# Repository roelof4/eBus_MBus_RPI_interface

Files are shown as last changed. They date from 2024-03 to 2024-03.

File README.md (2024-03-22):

# eBus_MBus_RPI_interface
Raspberry PI interface for eBus and M-Bus.

The interface combines a slave eBus interface and a master Mbus interface. This combination
is often present in heating systems such as gas boilers and heatpumps. For example, Vaillant
uses eBus to read and control.
The Mbus master is ideal to read heat meters, water meters and other sensors.
This interface provides power to the sensors and is thus classified as the master.
For safety purposes the eBus interface is fully galvanically shielded using optocouplers.

Both interfaces can be linked to serial (UART) ports on the Raspberry Pi. Version 4 and beyond
provide more than two UARTS and the user can select which one is used for either interface.
Older Raspberries can typically only use one UART. For these case the user can use serial to usb
cables using a separate 4-pin connector. Two are provided such that in principle the board
can be used standalone provided a 5V powersupply is present. When mounted as a HAT on the
Raspberry the 5V supply provided through the GPIO connector is used.

The interface also features a ONE WIRE sensor screw terminal which can act as a multiple temperature
sensor input (or whatever other ONE WIRE device available).

Note: the I2C EEPROM is optional and used for a system with automatic recognition.

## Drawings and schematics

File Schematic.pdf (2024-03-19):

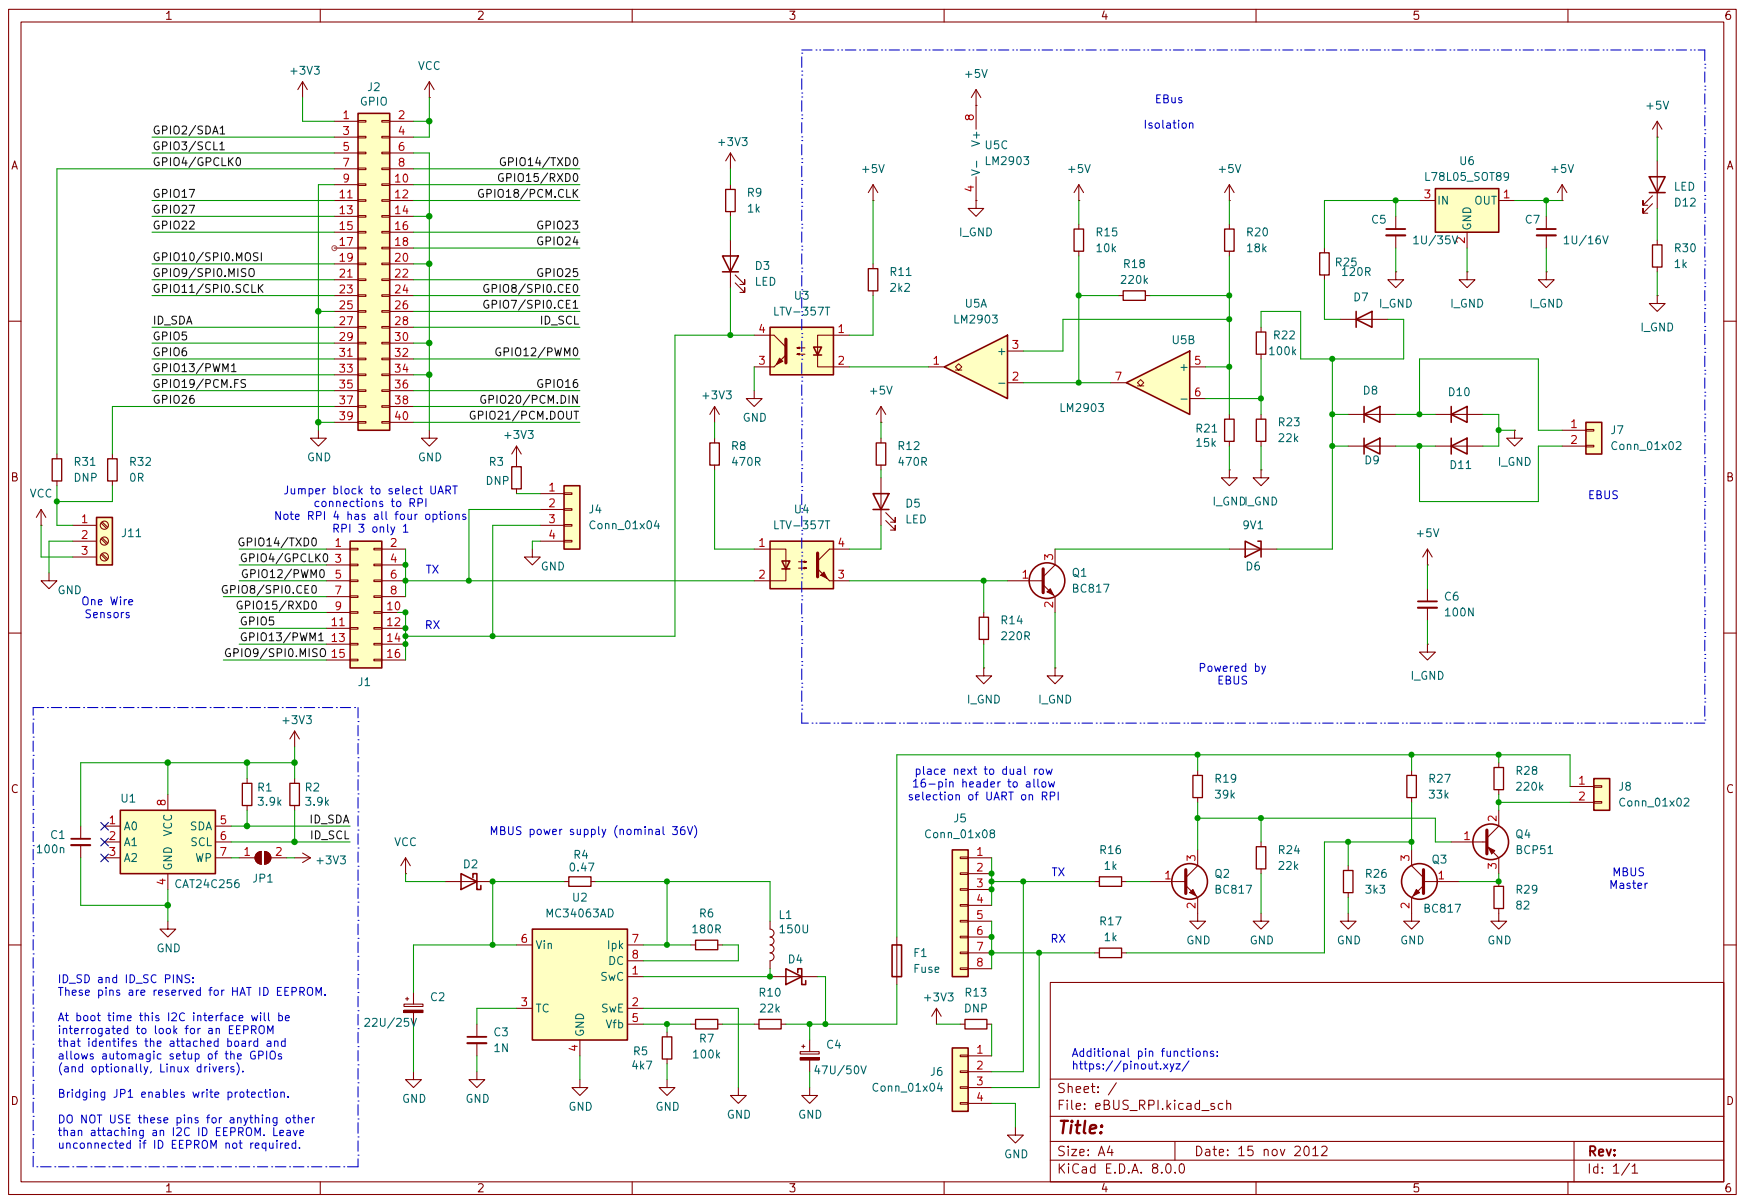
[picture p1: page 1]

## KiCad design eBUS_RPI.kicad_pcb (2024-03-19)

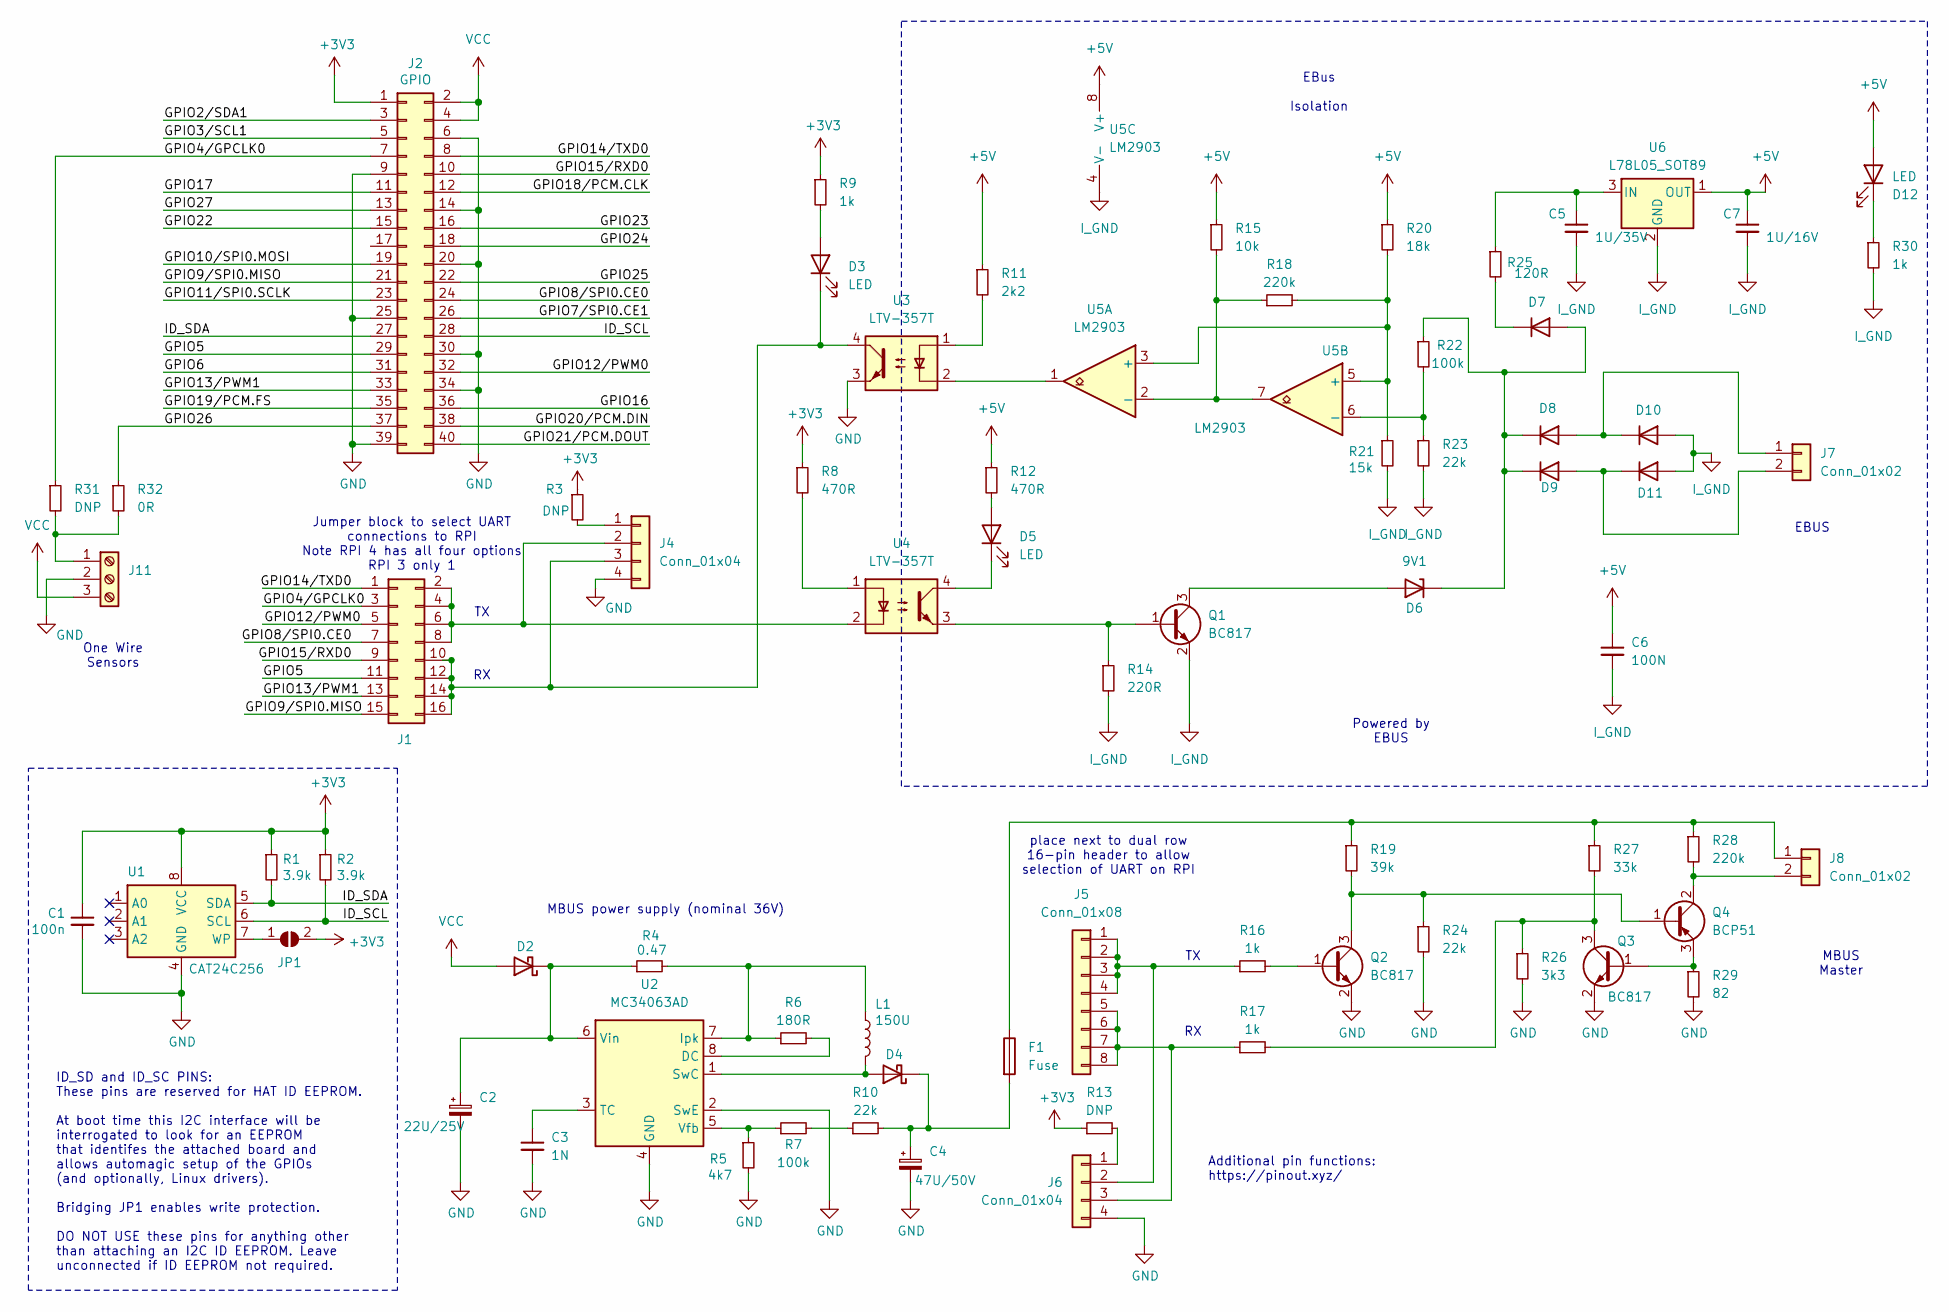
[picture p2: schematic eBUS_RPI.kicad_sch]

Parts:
C1: 100n; R_0603_1608Metric
C2: 22U/25V; CP_Elec_5x3.9
C3: 1N; C_0603_1608Metric
C4: 47U/50V; CP_Elec_5x5.7
C5: 1U/35V; C_0603_1608Metric
C6: 100N; C_0603_1608Metric
C7: 1U/16V; C_0603_1608Metric
D2, D4: D_Schottky; D_SMA
D3, D5, D12: LED; LED_0805_2012Metric
D6: 9V1; D_SMC
D7, D8, D9, D10, D11: BAS16W; SOT-323_SC-70
F1: Fuse; Fuse_2920_7451Metric
J1: Conn_02x08_Odd_Even; PinHeader_2x08_P2.54mm_Vertical
J2: GPIO; PinSocket_2x20_P2.54mm_Vertical
J4, J6: Conn_01x04; PinHeader_1x04_P2.54mm_Vertical
J5: Conn_01x08; PinHeader_1x08_P2.54mm_Vertical
J7, J8: Conn_01x02; PhoenixContact_MSTBA_2,5_2-G-5,08_1x02_P5.08mm_Horizontal
J11: Screw_Terminal_01x03; TerminalBlock_Phoenix_PT-1,5-3-5.0-H_1x03_P5.00mm_Horizontal
JP1: ID_WP; SolderJumper-2_P1.3mm_Open_TrianglePad1.0x1.5mm
L1: 150U; L_7.3x7.3_H4.5
Q1, Q2, Q3: BC817; SOT-23
Q4: BCP51; SOT-223-3_TabPin2
R1, R2: 3.9k; R_0603_1608Metric
R3, R13, R31: DNP; R_0603_1608Metric
R4: 0.47; R_0603_1608Metric
R5: 4k7; R_0603_1608Metric
R6: 180R; R_0603_1608Metric
R7, R22: 100k; R_0603_1608Metric
R8, R12: 470R; R_0603_1608Metric
R9, R16, R17, R30: 1k; R_0603_1608Metric
R10, R23, R24: 22k; R_0603_1608Metric
R11: 2k2; R_0603_1608Metric
R14: 220R; R_0603_1608Metric
R15: 10k; R_0603_1608Metric
R18, R28: 220k; R_0603_1608Metric
R19: 39k; R_0603_1608Metric
R20: 18k; R_0603_1608Metric
R21: 15k; R_0603_1608Metric
R25: 120R; R_0603_1608Metric
R26: 3k3; R_0603_1608Metric
R27: 33k; R_0603_1608Metric
R29: 82; R_0603_1608Metric
R32: 0R; R_0603_1608Metric
U1: CAT24C256; SOIC-8_3.9x4.9mm_P1.27mm
U2: MC34063AD; SOIC-8_3.9x4.9mm_P1.27mm
U3, U4: LTV-357T; SO-4_4.4x3.6mm_P2.54mm
U5: LM2903; SOIC-8_3.9x4.9mm_P1.27mm
U6: L78L05_SOT89; SOT-89-3

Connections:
+3V3: C1.1, J2.1, JP1.2 (B), R1.1, R2.1, R3.1, R8.1, R9.1, R13.1, U1.8 (VCC)
+5V: C6.1, C7.1, D12.2 (A), R11.1, R12.1, R15.1, R20.1, U5.8 (V+), U6.1 (OUT)
/GPIO2/SDA1: J2.3
/GPIO3/SCL1: J2.5
/GPIO4/GPCLK0: J1.3, J2.7, R31.1
/GPIO5: J1.11, J2.29
/GPIO6: J2.31
/GPIO7/SPI0.CE1: J2.26
/GPIO8/SPI0.CE0: J1.7, J2.24
/GPIO9/SPI0.MISO: J1.15, J2.21
/GPIO10/SPI0.MOSI: J2.19
/GPIO11/SPI0.SCLK: J2.23
/GPIO12/PWM0: J1.5, J2.32
/GPIO13/PWM1: J1.13, J2.33
/GPIO14/TXD0: J1.1, J2.8
/GPIO15/RXD0: J1.9, J2.10
/GPIO16: J2.36
/GPIO17: J2.11
/GPIO18/PCM.CLK: J2.12
/GPIO19/PCM.FS: J2.35
/GPIO20/PCM.DIN: J2.38
/GPIO21/PCM.DOUT: J2.40
/GPIO22: J2.15
/GPIO23: J2.16
/GPIO24: J2.18
/GPIO25: J2.22
/GPIO26: J2.37, R32.1
/GPIO27: J2.13
/ID_SCL: J2.28, R2.2, U1.6 (SCL)
/ID_SDA: J2.27, R1.2, U1.5 (SDA)
GND: C1.2, C2.2, C3.2, C4.2, J2.6, J2.9, J2.14, J2.20, J2.25, J2.30, J2.34, J2.39, J4.4, J6.4, J11.2, Q2.2 (E), Q3.2 (E), R5.2, R24.2, R26.2, R29.2, U1.4 (GND), U2.2 (SwE), U2.4 (GND), U3.3
I_GND: C5.2, C6.2, C7.2, D10.1 (A), D11.1 (A), Q1.2 (E), R14.2, R21.2, R23.2, R30.2, U5.4 (V-), U6.2 (GND)
unnamed: C2.1, D2.1 (K), R4.1, U2.6 (Vin)
unnamed: D3.2 (A), R9.2
unnamed: D3.1 (K), J1.10, J1.12, J1.14, J1.16, J4.3, U3.4
unnamed: D4.2 (A), L1.2, U2.1 (SwC)
unnamed: C4.1, D4.1 (K), F1.2, R10.2
unnamed: D5.2 (A), R12.2
unnamed: D5.1 (K), U4.4
unnamed: D6.2 (A), Q1.3 (C)
unnamed: D6.1 (K), D7.1 (A), D8.3 (K), D9.3 (K), R22.1
unnamed: D7.3 (K), R25.2
unnamed: D8.1 (A), D10.3 (K), J7.1
unnamed: D9.1 (A), D11.3 (K), J7.2
unnamed: D12.1 (K), R30.1
unnamed: J1.2, J1.4, J1.6, J1.8, J4.2, U4.2
unnamed: J4.1, R3.2
unnamed: J5.1, J5.2, J5.3, J5.4, J6.2, R16.1
unnamed: J5.5, J5.6, J5.7, J5.8, J6.3, R17.1
unnamed: J6.1, R13.2
unnamed: F1.1, J8.1, R19.1, R27.1, R28.1
unnamed: J8.2, Q4.2 (C), R28.2
unnamed: J11.1, R31.2, R32.2
unnamed: JP1.1 (A), U1.7 (WP)
unnamed: Q1.1 (B), R14.1, U4.3
unnamed: Q2.1 (B), R16.2
unnamed: Q2.3 (C), Q4.1 (B), R19.2, R24.1
unnamed: Q3.1 (B), Q4.3 (E), R29.1
unnamed: Q3.3 (C), R17.2, R26.1, R27.2
unnamed: R8.2, U4.1
unnamed: R7.2, R10.1
unnamed: R11.2, U3.1
unnamed: R6.2, U2.8 (DC)
unnamed: L1.1, R4.2, R6.1, U2.7 (Ipk)
unnamed: C3.1, U2.3 (TC)
unnamed: R5.1, R7.1, U2.5 (Vfb)
unnamed: U3.2, U5.1
unnamed: R18.2, R20.2, R21.1, U5.3 (+), U5.5 (+)
unnamed: R15.2, R18.1, U5.2 (-), U5.7
unnamed: R22.2, R23.1, U5.6 (-)
unnamed: C5.1, R25.1, U6.3 (IN)
VCC: D2.2 (A), J2.2, J2.4, J11.3

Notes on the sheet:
Powered by EBUS
One Wire Sensors
MBUS Master
EBUS
place next to dual row 16-pin header to allow selection of UART on RPI
ID_SD and ID_SC PINS: These pins are reserved for HAT ID EEPROM. At boot time this I2C interface will be interrogated to look for an EEPROM that identifes the attached board and allows automagic setup of the GPIOs (and optionally, Linux drivers). Bridging JP1 enables write protection. DO NOT USE th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
MBUS power supply (nominal 36V)
EBus Isolation
Additional pin functions: https://pinout.xyz/
Jumper block to select UART connections to RPI Note RPI 4 has all four options RPI 3 only 1

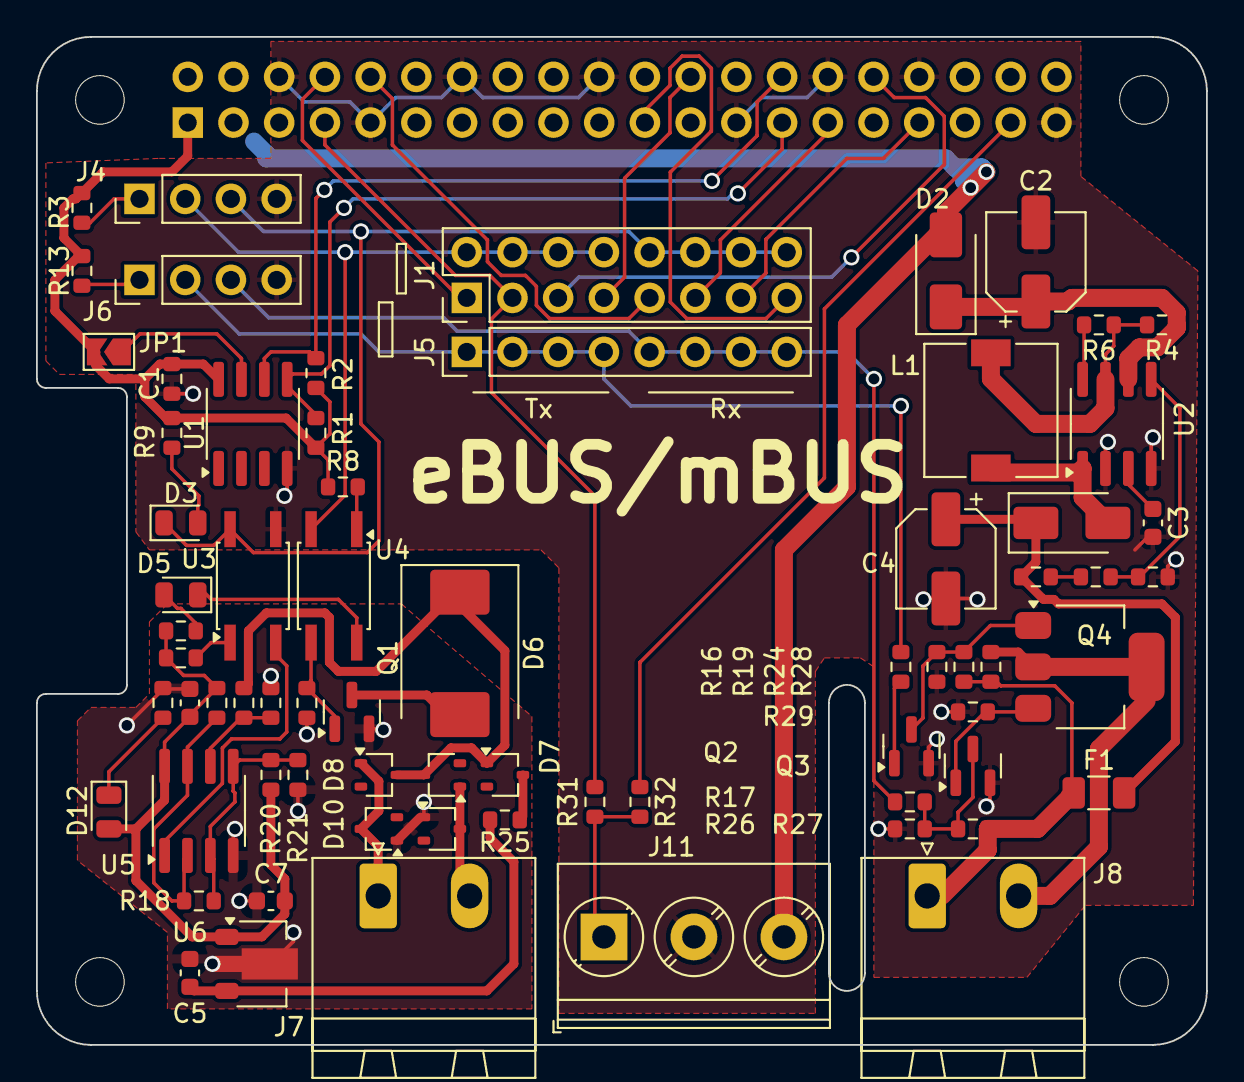
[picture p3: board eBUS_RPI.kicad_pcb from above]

Board: 2 copper layers, 65.0 x 56.0 mm, 75 parts (1 on the bottom side), 55 nets.

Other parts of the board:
MH1, MH2, MH3, MH4: MountingHole_2.7mm_M2.5
